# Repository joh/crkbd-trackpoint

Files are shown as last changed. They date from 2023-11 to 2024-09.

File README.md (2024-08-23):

# crkbd trackpoint

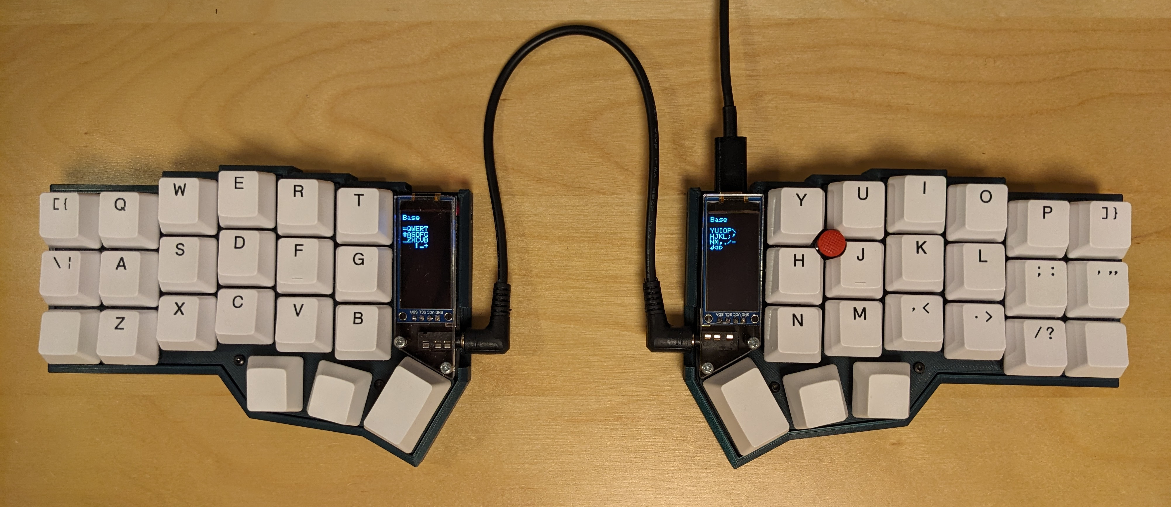
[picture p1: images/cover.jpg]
crkbd trackpoint


I added a trackpoint to a [corne-cherry](https://github.com/foostan/crkbd) (crkbd) keyboard for ergonomic pointing bliss.

The trackpoint is mounted in the middle of the YUHJ keys for easy access from the home row.
Luckily, the corne-cherry PCB has a mounting hole at this exact location, which we repurpose for the trackpoint.

## Hardware
- [corne-cherry kit](https://github.com/foostan/crkbd)
- [Sprintek SK8707 trackpoint module](https://www.sprintek.com/en/products/pointing_stick/SK8707-06.aspx)
- Suitable trackpoint stem
- RP2040 controller, e.g., [SparkFun Pro Micro - RP2040](https://www.sparkfun.com/products/18288) or [Adafruit KB2040](https://www.adafruit.com/product/5302)
- 64x128 OLED module (SH1107)
- 3D-printed case, switch plates, tenting legs (optional) and wrist rest (optional)
- Keycaps

### SK8707 trackpoint module
Can be ordered directly from Sprintek by [sending them an email](https://www.sprintek.com/en/order/Order.aspx).
There is a 5V and 3.3V version.
Get the 3.3V version to be compatible with the RP2040.
I accidentally ordered the 5V version, so I had to bypass the 5V regulator and hooked up 3.3V from the RP2040 to Vout on the board (see photo below).

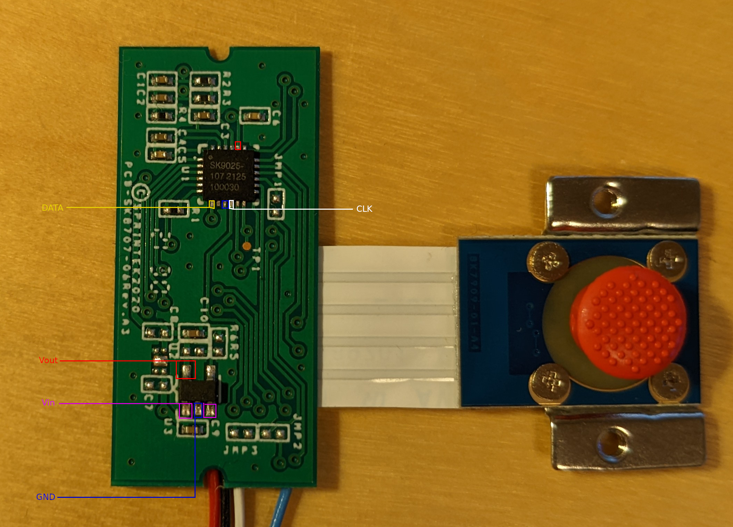
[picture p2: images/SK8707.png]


I desoldered the ribbon cable from the controller board, and wired up only the four wires needed:
- Pin 1: PS/2 data line (blue)
- Pin 6: PS/2 clock line (white)
- Pin 7: GND (black)
- Pin 8: 3.3V (red, if you got the 3.3V version)
- Vout: 3.3V (red, if you got the 5V version)

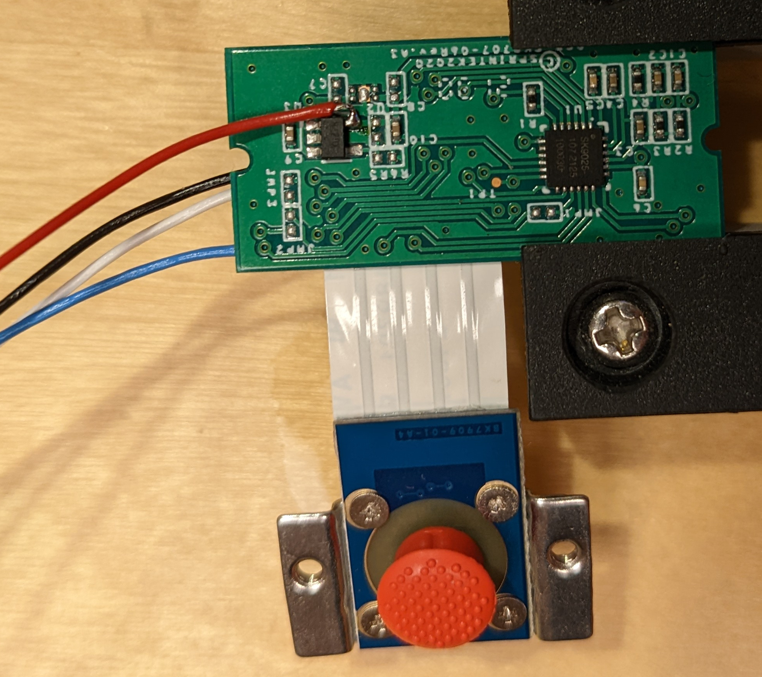
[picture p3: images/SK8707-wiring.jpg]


SK8707 does not require a reset circuit, but it does need pullups on the PS/2 data and clock lines. We can enable pullups on the RP2040 controller, so no extra resistors are needed (see [this commit](https://github.com/joh/qmk_firmware/commit/aa0214f5b1b3001cf7cc99419c32c8b87707cb5a)).

I was lucky to have a trackpoint stem from a decommissioned Tex Yoda II, but others report success using a [labret cheek piercing](https://github.com/alonswartz/trackpoint#q-what-should-i-use-for-the-trackpoint-stemstick).

### RP2040 controller
At first I tried using an AVR-based controller (Elite C with ATMega32U4).
The crkbd occupies the USART pin (D2) for soft serial, so we're stuck with QMKs PS/2 interrupt mode (unless we hack the PCB).
Unfortunately, I found that quite frequently PS/2 packets would arrive with parity errors.
After some investigation, I was able to track it down to [QMK interrupts sometimes being delayed and missing the PS/2 clock altogether](https://www.reddit.com/r/olkb/comments/xppdsz/ps2_interrupt_delays_on_avr/).

Instead of hacking the PCB, it's much easier to upgrade the controller.
This also leaves ample room for other features.
There are several options that are pin-compatible with the Pro Micro.
The RP2040-based boards are not only powerful, but come with Programmable IO (PIO) hardware blocks.
PIO enables protocols such as PS/2 to be implemented in hardware, offloading the main processor for more important work.
A PS/2 PIO driver is now available in QMK (developed by @gamelaster and myself, see [PR #17893](https://github.com/qmk/qmk_firmware/pull/17893)).

Make the following connections from the SK8707:
* PS/2 data line: connect to pin 8 on the RP2040
* PS/2 clock line: connect to pin 9 on the RP2040
* 3.3V and GND are readily available from the OLED header

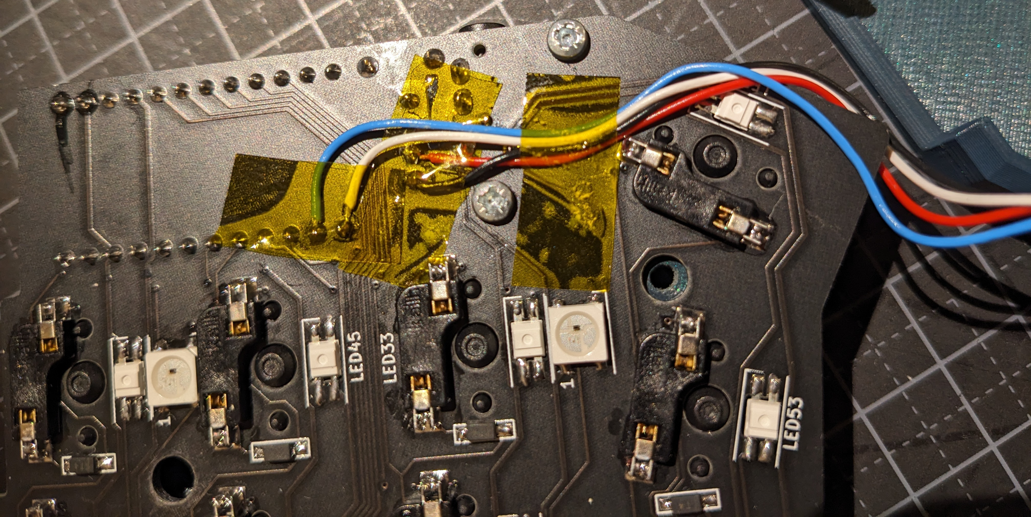
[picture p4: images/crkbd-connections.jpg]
crkbd connections


### 64x128 OLED module (SH1107)

While not directly related to the trackpoint, I upgraded to larger 64x128 OLED modules (SH1107).
These are wide enough so that the entire keymap can be displayed (reflecting the current layer), which is extremely handy.
I also use them to display the current trackpoint sensitivity.
Search AliExpress and you will find plenty of options.

### 3D-printed case

To mount the trackpoint, I designed a 3D-printed case based on the [Travel Crkbd magnetic case by taksi_kavausuki](https://www.printables.com/model/117598-travel-crkbd-magnetic-case).
There is one version of the case without trackpoint (for the left half) and one version with the trackpoint mount (for the right half).
The switch plates are remixed from [Corne Keyboard HiPro Case by mburrows](https://www.thingiverse.com/thing:3652379).

STLs and sources can be found under `STLs/` and `sources/`, respectively.

Some notable features:
* Trackpoint mount (for the right half)
* Insets for 8mm anti-slip pads
* Attachable tenting legs (optional)
* Attachable wrist rests (optional)

STLs:
* `Case_Trackpoint.stl`: Case with trackpoint mount (right half)
* `Case_Normal.stl`: Case without trackpoint mount (left half)
* `Switch_Plate_Trackpoint.stl`: Switch plate for trackpoint
* `Switch_Plate_Normal.stl`: Switch plate without trackpoint
* `Wrist_Rest.stl`: Wrist rest (optional)
* `Leg_50mm.stl` and `Leg_42_5mm.stl`: Tenting legs (optional)

#### Required hardware
* 9x M2 heated inserts
* 9x M2x10 screws
* 2x M2x4 screws
* 2x M2 nuts
* 8x M3nS square nuts (tenting legs and wrist rests)
* 10x M3x10 screws (tenting legs and wrist rests)
* 2x M3 heated inserts (tenting legs on wrist rests)
* 8mm anti-slip pads

#### Printing instructions
Print the parts in your favorite material.
I used PLA with 0.15mm layer height, 4 perimeters and 15% infill.

`Case_Trackpoint.stl` should be printed with supports below the trackpoint mount (add a support enforcer modifier).
For `Wrist_Rest.stl`, add some extra infill around the heated insert (add an infill modifier).

**NB: The parts are all oriented for the left half, so to print the right halves simply mirror each part accordingly in the slicer.**

#### License

The 3D-printed files are licensed under [CC BY-NC-SA 4.0](https://creativecommons.org/licenses/by-nc-sa/4.0/)
[](https://creativecommons.org/licenses/by-nc-sa/4.0/)

### Assembly

The instructions below are for the trackpoint version of the case.

Using a soldering iron, insert the M2 heated inserts into the case:
case trackpoint top

If you would like to use tenting legs, insert M3ns square nuts in the two slots on the left side inside the case.
If you plan on attaching wrist rests, insert M3ns square nuts in the two slots on the bottom side inside the case.
Tip: Use a M3 screw to pull the nuts in.

Turn the case over and insert two M2 nuts for mounting the trackpoint:
case trackpoint bottom

In the above photo you can see the insets for the anti-slip pads.
Attach as many as appropriate (if tenting, you only need pads along the outer edge).

Attach the SK8707 trackpoint module with two M2x4 screws:
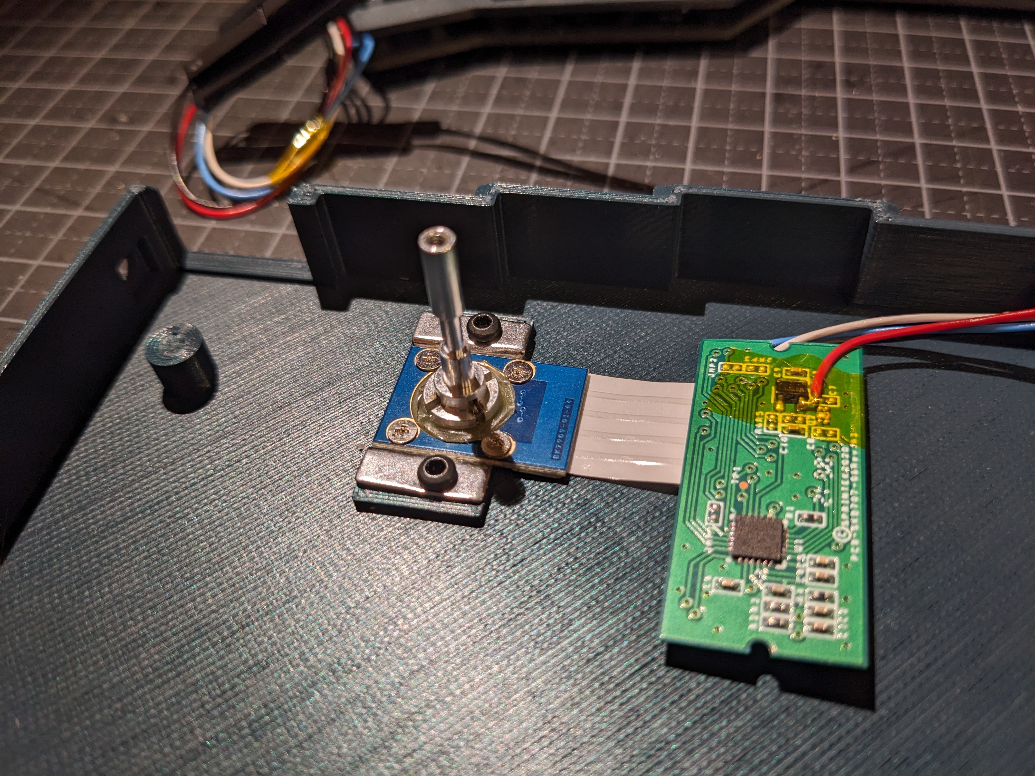
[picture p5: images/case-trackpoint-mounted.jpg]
case trackpoint mounted


Attach the SK8707 PCB with double-sided tape, and route the wires as follows:
case trackpoint wiring

Insert the crkbd PCB with the 3D-printed switch plate and attach with four M2x10 screws.
Make sure the trackpoint wires are not pinched!
Note: the PCB switch plate and bottom plate that come with the corne cherry kit are not used.
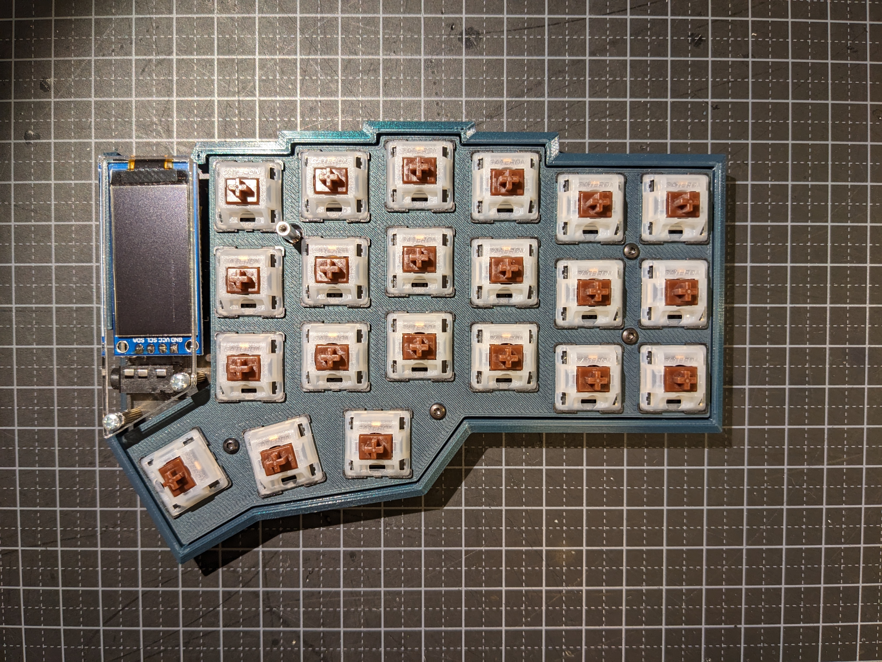
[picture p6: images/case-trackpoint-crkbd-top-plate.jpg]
case trackpoint wiring


The YUHJ keycaps must be modified to make room for the trackpoint stem (see below for jig).
Here the stem sports a 3D-printed adapter for the trackpoint cap.
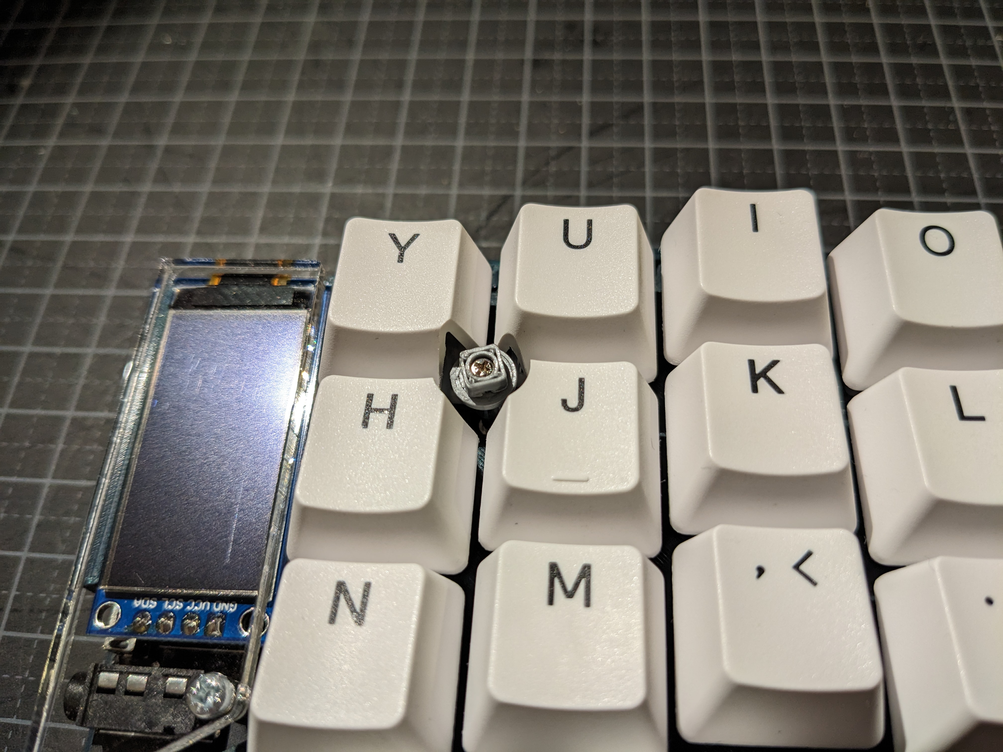
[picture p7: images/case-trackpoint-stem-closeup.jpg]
case trackpoint stem closeup


With the cap it looks rather neat:
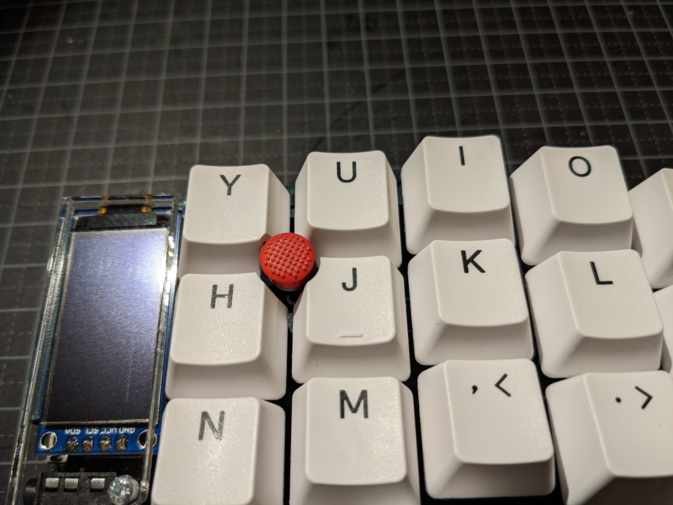
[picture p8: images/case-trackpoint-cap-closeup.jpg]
case trackpoint cap closeup


The finished product:
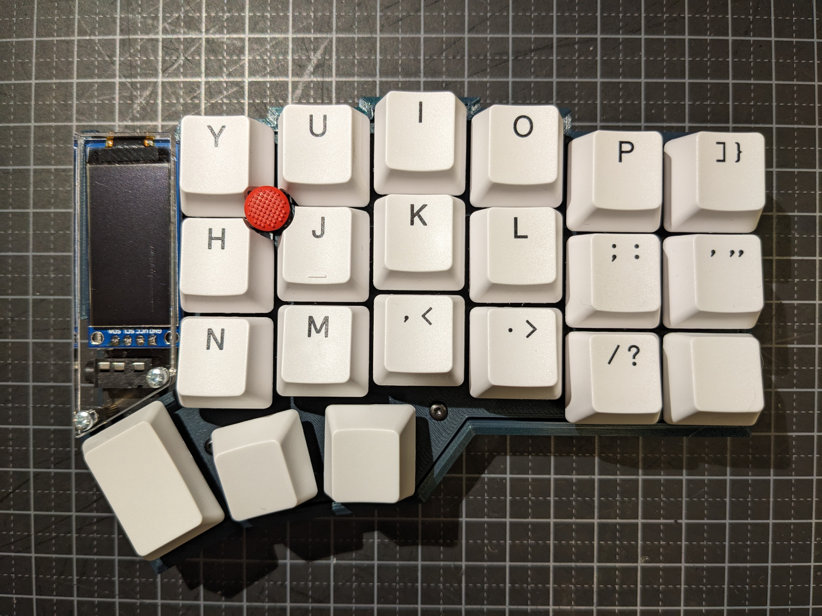
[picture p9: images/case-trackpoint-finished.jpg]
case trackpoint finished


Repeat the above process for the other half (excluding the trackpoint, of course).

Tenting legs can be customized to any height in OpenSCAD, and attach to the side of the keyboard:
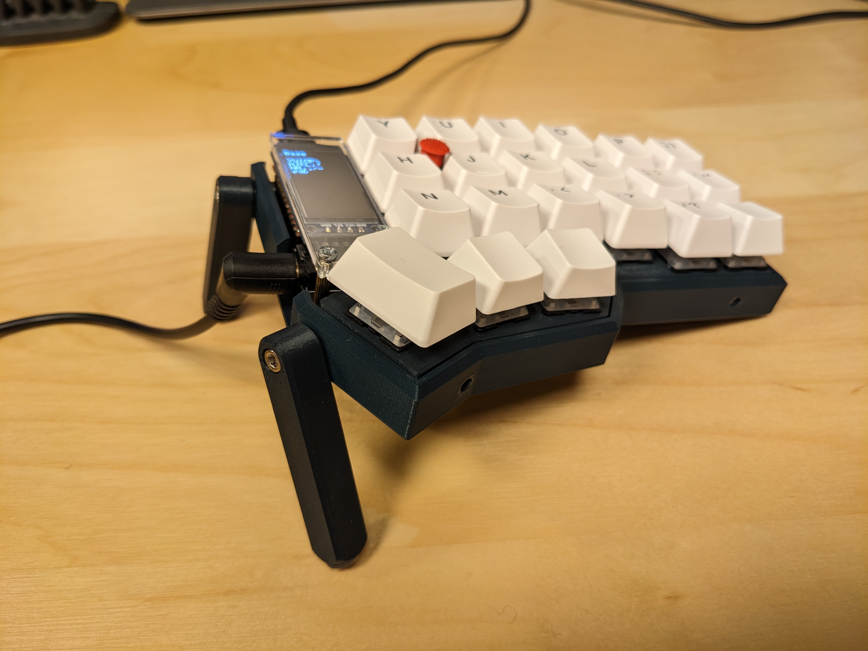
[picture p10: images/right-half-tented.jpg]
crkbd trackpoint tented


Using the trackpoint is most comfortable using a wrist rest.
The wrist rest also helps prevent the keyboard from being pushed across the desk while using the trackpoint.
For comfort, I attached some 5mm neoprene pads.
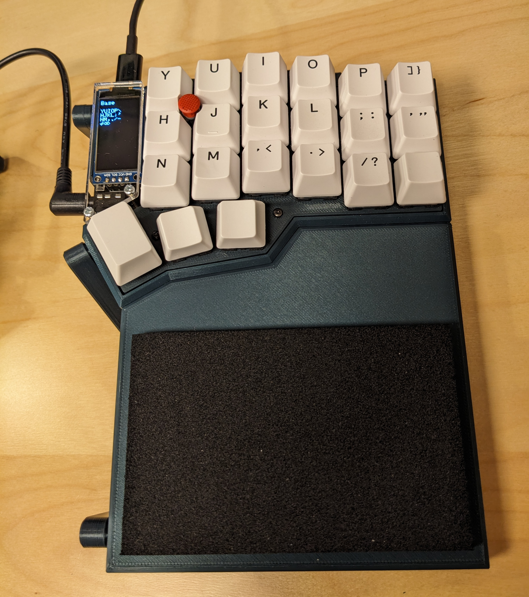
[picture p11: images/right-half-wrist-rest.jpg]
crkbd trackpoint with wrist rest


Both halves with wrist rests and tenting:
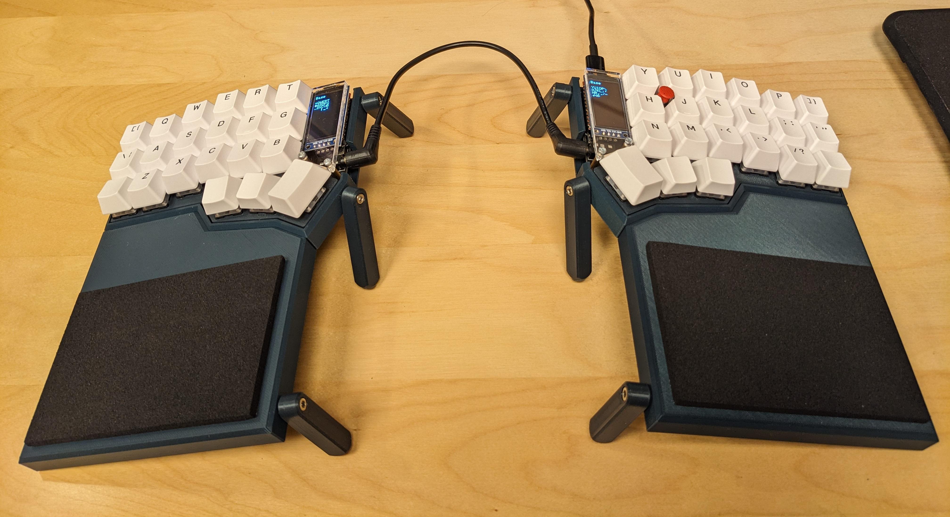
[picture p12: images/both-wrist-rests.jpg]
both halves with wrist rests and tenting


### YUHJ drilling jig

There is also a 3D-printable jig available for help modifying the YUHJ keycaps to accomodate the trackpoint.
Place the YUHJ keys between the top and bottom plate, and fasten the plates together with some screws.
Then use the hole as a guide to file / Dremel away a small part of each key.

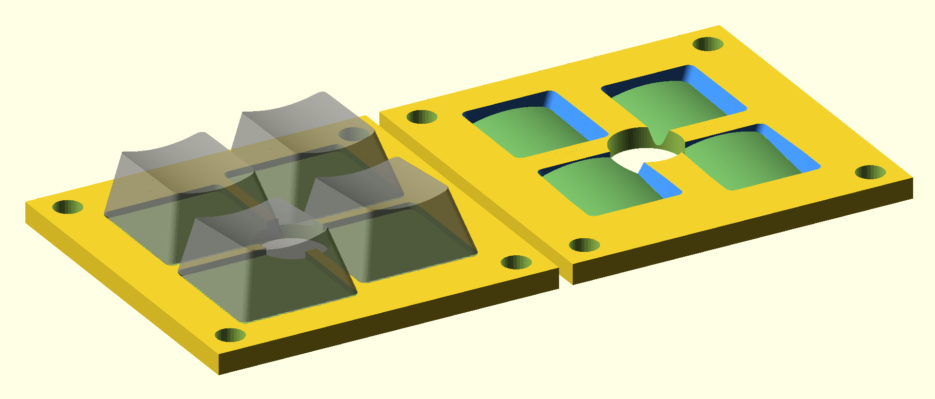
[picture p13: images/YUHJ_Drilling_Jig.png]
YUHJ drilling jig


STLs:
* `YUHJ_Drilling_Jig_Bottom.stl`
* `YUHJ_Drilling_Jig_Top.stl`

The jig can be customized for different keycap profiles, see `YUHJ_Drilling_Jig.scad`.

### Firmware
Please see my [qmk branch](https://github.com/joh/qmk_firmware/tree/joh-rp2040-trackpoint-pio-v4/keyboards/crkbd/keymaps/joh) for details on how to configure QMK.

Some notable features:
* `MH_AUTO_MOUSE_BUTTONS` from manna-harbour is used to automatically switch to the mouse layer when the trackpoint is used.
* Pullups are enabled on the PS2 CLK/DATA pins (see [this commit](https://github.com/joh/qmk_firmware/commit/aa0214f5b1b3001cf7cc99419c32c8b87707cb5a))
* Custom keys for controlling trackpoint sensitivity

## Other resources
This project was largely inspired by manna-harbours [crkbd hotstwap trackpoint](https://github.com/manna-harbour/crkbd).
Other good sources of information:
* [jorne trackpoint](https://github.com/joric/jorne/wiki/Trackpoint)
* [How to integrate a trackpoint in a mechanical keyboard by alonswartz](https://github.com/alonswartz/trackpoint)
* [TPS42 keyboard](https://kbd.news/TPS42-1711.html)

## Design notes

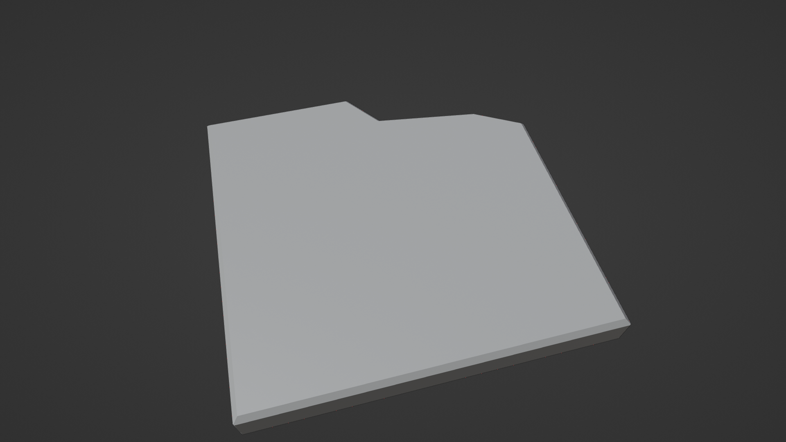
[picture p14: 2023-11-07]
images/Wrist_Rest.png

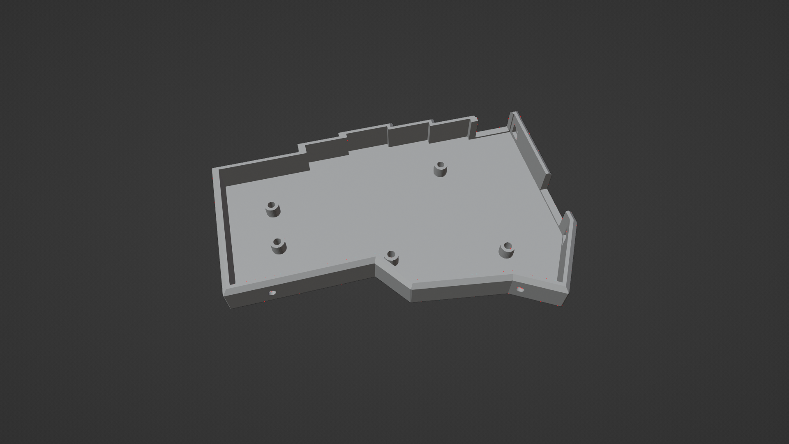
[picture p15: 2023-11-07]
images/Case_Normal.png

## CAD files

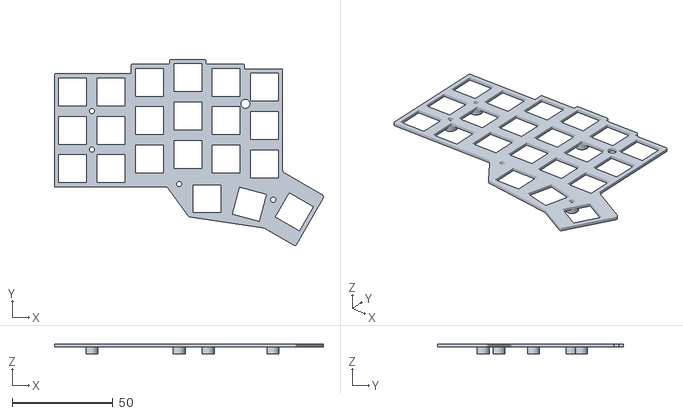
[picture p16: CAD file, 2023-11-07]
STLs/Switch_Plate_Trackpoint.stl
133.2 x 92.2 x 4.90

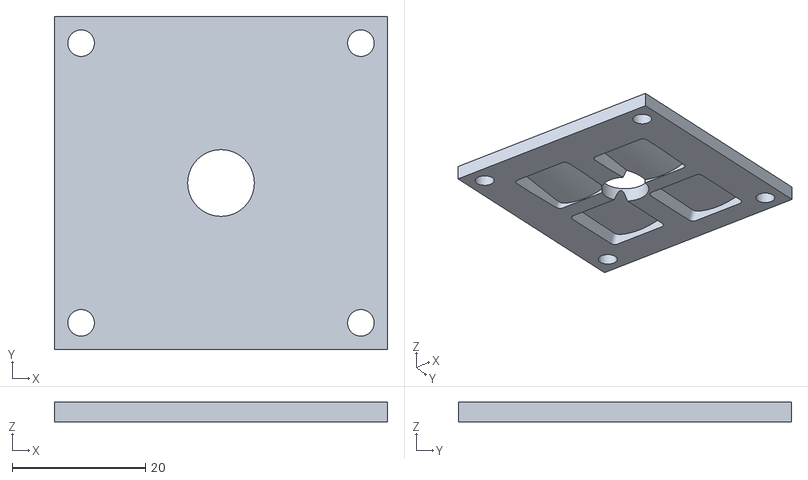
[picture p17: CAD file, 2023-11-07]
STLs/YUHJ_Drilling_Jig_Top.stl
50.0 x 50.0 x 3.00

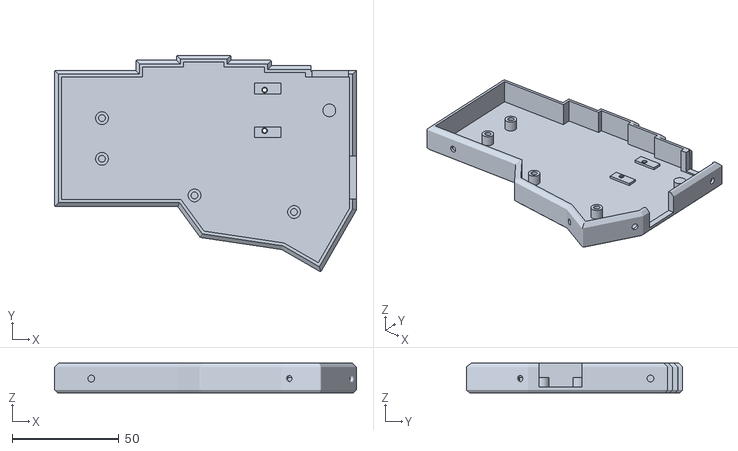
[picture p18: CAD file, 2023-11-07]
STLs/Case_Trackpoint.stl
141.2 x 101.1 x 13.8

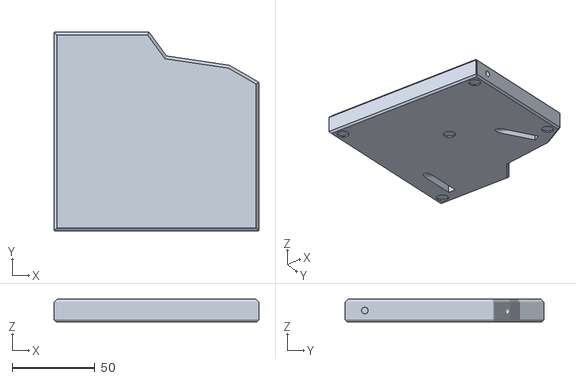
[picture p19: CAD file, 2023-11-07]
STLs/Wrist_Rest.stl
124.1 x 120.4 x 13.8

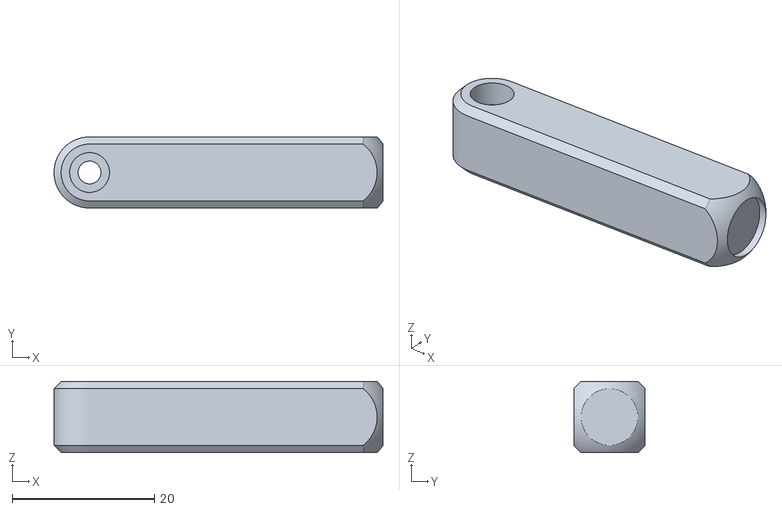
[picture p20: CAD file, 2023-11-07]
STLs/Leg_42_5mm.stl
46.3 x 10.0 x 10.0

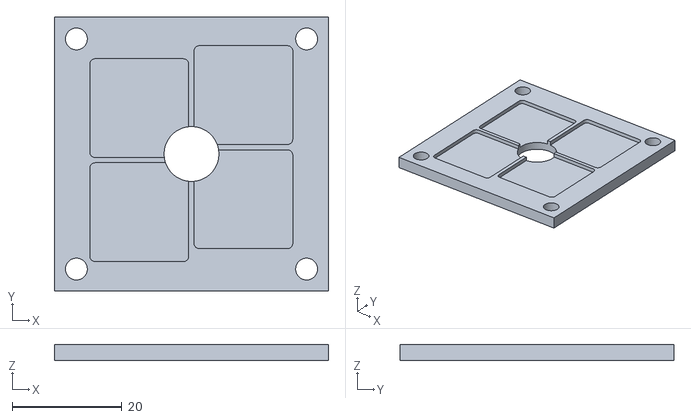
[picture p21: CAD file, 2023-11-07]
STLs/YUHJ_Drilling_Jig_Bottom.stl
50.0 x 50.0 x 3.00

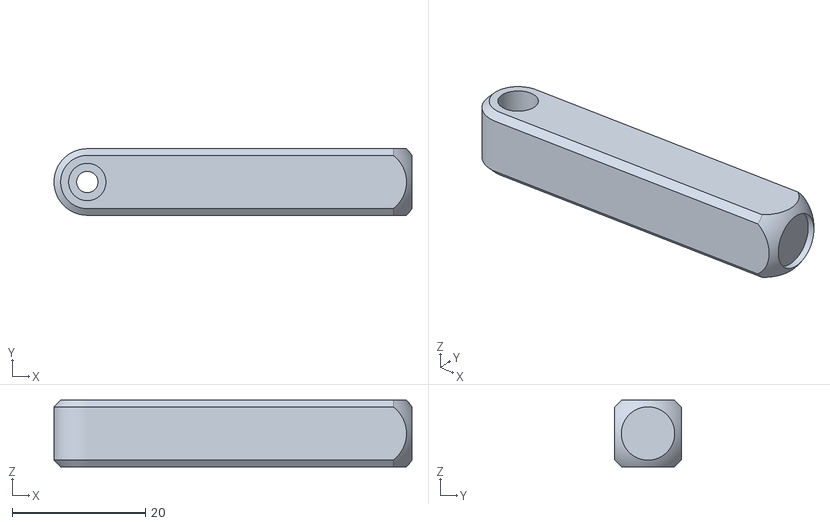
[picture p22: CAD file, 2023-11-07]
STLs/Leg_50mm.stl
53.8 x 10.0 x 10.0

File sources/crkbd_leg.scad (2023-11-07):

/*
 * Tenting leg for crkbd_trackpoint_case
 */
include <Chamfers-for-OpenSCAD/Chamfer.scad>;

// Leg thickness (height)
thickness=10;

// Leg length (from screw center to bottom, including pad)
length=42.5;

// Diameter of screw hole
screw_dia=3.2;

// Diameter of screw head inset
screw_head_dia=5.6;

// Depth of screw head inset
screw_head_inset=thickness - 6.8;

// Diameter of anti-slip pad
pad_dia=8;

// Depth of inset for anti-slip pad
pad_depth=1;

// Chamfer
ch = 1;

$fn=360;

difference() {
    r = max(screw_head_dia/2 + 2, thickness/2);
    d = sqrt(2)*thickness;
    chamfers = [[1, 1, 1, 1], [0, 0, 0, 0], [0, 0, 0, 0]];
    union() {
        chamferCylinder(h=thickness, r=r, ch=ch);
        translate([0, -thickness/2, 0])
            chamferCube([length-thickness/2, thickness, thickness], chamfers, ch);

        translate([length-d/2, 0, thickness/2])
        intersection() {
            sphere(d=d);
            translate([0, -thickness/2, -thickness/2])
            chamferCube([thickness, thickness, thickness], chamfers, ch);
        }
    }

    translate([0, 0, thickness-screw_head_inset])
        cylinder(h=100, d=screw_head_dia);
    cylinder(h=100, d=screw_dia, center=true);

    s = (d/2) - sqrt((d/2)^2 - (pad_dia/2)^2);
    translate([(length-s-pad_depth), 0, thickness/2])
    rotate([0, 90, 0])
        cylinder(h=100, d=pad_dia);
}

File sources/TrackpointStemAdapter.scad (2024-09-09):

cube_width        = 4.3; // measured: 4.5
cube_height       = 2.4; // measured: 2.4
base_dia          = 7.0; // measured: 7.0
base_height       = 3.6; // measured: 0.6
bottom_hole_dia   = 3.3; // measured: 3.1
bottom_hole_depth = 2.0; // measured: 2.0
hole_dia          = 2.0; // measured: 1.8
screw_head_dia    = 2.7; // measured: 2.5
screw_head_depth  = 3.0; // measured: 3.0

$fn = 60;

difference() {
union() {
translate([-cube_width/2, -cube_width/2, base_height])
cube([cube_width, cube_width, cube_height]);

cylinder(d=base_dia, h=base_height);
}

translate([0, 0, -bottom_hole_depth])
cylinder(d=bottom_hole_dia, h=2*bottom_hole_depth);

cylinder(d=hole_dia, h=10);

translate([0, 0, screw_head_depth])
cylinder(d=screw_head_dia, h=10);
}

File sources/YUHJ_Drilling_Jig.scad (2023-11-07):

// the point of this file is to be a sort of DSL for constructing keycaps.
// when you create a method chain you are just changing the parameters
// key.scad uses, it doesn't generate anything itself until the end. This
// lets it remain easy to use key.scad like before (except without key profiles)
// without having to rely on this file. Unfortunately that means setting tons of
// special variables, but that's a limitation of SCAD we have to work around

include <./KeyV2/includes.scad>


// example key
/*dcs_row(5) legend("⇪", size=9) key();*/

// example row
/* for (x = [0:1:4]) {
  translate_u(0,-x) dcs_row(x) key();
} */

// example layout
//preonic_default("oem") key();
//60_percent_default("oem") key();
/*translate([0, $unit/2, 0])*/
/*planck_default("oem") key();*/

// The stem is the hardest part to print, so this variable controls how much 'slop' there is in the stem
// if your keycaps stick in the switch raise this value
//$stem_slop = 0.35; // Not working in thingiverse customizer atm [0:0.01:1]
// broke this out. if your keycaps are falling off lower this value. only works for cherry stems rn
$stem_inner_slop = 0.25;
$stem_inset = 0;

$unit = 19;
$dy = 2.38;

plate_size = 50;
plate_thickness = 3;
plate_hole = 4;

module plate_hole() {
    cylinder(d=plate_hole, h=100, center=true);
}

module plate_holes() {
    translate([-plate_size/2 + plate_hole, plate_size/2 - plate_hole, 0])
    plate_hole();

    translate([-plate_size/2 + plate_hole, -plate_size/2 + plate_hole, 0])
    plate_hole();

    translate([plate_size/2 - plate_hole, -plate_size/2 + plate_hole, 0])
    plate_hole();

    translate([plate_size/2 - plate_hole, plate_size/2 - plate_hole, 0])
    plate_hole();
}

module plate() {
    translate([-plate_size/2, -plate_size/2, 0])
    cube([plate_size, plate_size, plate_thickness]);
}

module top_plate() {
    difference() {
        translate([0, 0, 7])
        plate();
        keys();
        plate_holes();
        trackpoint_hole();
    }
}

module bottom_plate() {
    difference() {
        translate([0, 0, -plate_thickness+1])
        plate();
        keys_slot();
        //keys();
        plate_holes();
        trackpoint_hole();
    }
};

bottom_plate();
translate([plate_size+2, 0, 8])
rotate([0,180,0])
top_plate();
color("gray", .75)
keys();

module keys_slot() {
    linear_extrude(height=4, convexity=2)
    projection()
    keys();
}

module keys() {
    union() {
        translate([-9.54, 8.37, 0])
        //oem_row(1) legend("Y") key();
        oem_row(1) outer_total_shape(false);

        translate([9.47, 10.75, 0])
        //oem_row(1) legend("U") key();
        oem_row(1) outer_total_shape(false);

        translate([-9.53, -10.62, 0])
        //oem_row(2) legend("H") key();
        oem_row(2) outer_total_shape(false);

        translate([9.47, -8.25, 0])
        //oem_row(2) legend("J") key();
        oem_row(2) outer_total_shape(false);
    }
};

module trackpoint_hole() {
    cylinder(d=10, h=40, center=true, $fn=90);
}

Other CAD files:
STLs/Switch_Plate_Normal.stl
STLs/Case_Normal.stl
sources/crkbd_trackpoint_case.blend

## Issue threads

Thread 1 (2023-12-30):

It works until the keyboard gets disconnected, then it is hit and miss whether it will start working again.

BenBKirk, 2023-12-30:
Hi Joh,

Thank you for uploading this guide, I wouldn't have been able to get my trackpoint working without it.

Here is a picture of my Corne with the trackpoint placed in the thumb position:
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

I upgraded to RP2040 with the following pinout:
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

Flashing your keymap straight into the keyboard made everything work but when I unplug the keyboard, or the computer sleeps or I reset the board, it becomes unresponsive. This happens on windows 11 and arch linux. From the OS the device is still connected, it just doesn't do anything. As if it crashed but the green light stays on the microcontrollers. If I then reset the board a few times it connects every 5 tries or so and everything works fine including the trackpoint, until I disconnect the keyboard or shutdown the laptop.

Have you ever experienced a similar issue?
The only difference that I can see between our builds is that I am using a different trackpoint and I have made a small reset circuit for it by following this guide https://rfong.github.io/rflog/2021/10/26/r61-trackpoint-pt2/ .

Would appreciate any input for how I could troubleshoot this.

Thanks,
Ben

joh, 2024-01-03:
Hi, looks like a clean build! I have not experienced the issue you're describing, but here's a few things to try:

1. Does it work with the trackpoint disabled? (set `TRACKPOINT_ENABLE = no` in `keyboards/crkbd/keymaps/joh/rules.mk`)
2. If not, does it work if you disconnect the trackpoint clock and data wires?
3. I believe your trackpoint module (R61) is 5V I/O, but the RP2040 is 3.3V and the GPIO pins cannot safely handle 5V. You need a level shifter between the trackpoint CLK/DATA lines and the RP2040 GPIO pins.

BenBKirk, 2024-01-10:
Thanks for the advice.
I had already unsoldered the trackpoint by the time you replied and as expected there was no more crashing even without changing anything in the code.
I was under the impression that a 5v trackpoint would still work at 3.3v as mentioned [here](https://github.com/joric/jorne/wiki/Trackpoint#t60t400-trackpoint) but what you are saying makes sense, maybe I should look for a 3.3V trackpoint module.

Something also worth mentioning, I also have pull-up resistors for data and clock wires but noticed that you did this in the code somewhere instead. how did you do this and do I need to disable it?

joh, 2024-01-11:
> I was under the impression that a 5v trackpoint would still work at 3.3v as mentioned [here](https://github.com/joric/jorne/wiki/Trackpoint#t60t400-trackpoint) but what you are saying makes sense, maybe I should look for a 3.3V trackpoint module.

I'm not sure I understand what that page says about 3.3V. Does it say 5V and 3.3V logic levels are compatible? Or perhaps powering the R61 off 3.3V should work?

> Something also worth mentioning, I also have pull-up resistors for data and clock wires but noticed that you did this in the code somewhere instead. how did you do this and do I need to disable it?

You're right, two pullups could be causing problems. The 3.3V pullup was added in [aa0214f](https://github.com/joh/qmk_firmware/commit/aa0214f5b1b3001cf7cc99419c32c8b87707cb5a). You can try reverting that commit, keeping your external pullup (`git revert aa0214f`)

joh, 2024-08-23:
Closing due to inactivity.

Closed 2024-08-23.

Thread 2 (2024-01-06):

Where are pins B4 and B5 on the RP2040? For the PS/2 clock and data lines.

bluepylons, 2024-01-06:
The README states the following for the Trackpoint connections:

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

What pins are these referring to? I can't find any RP2040 boards with that pin naming scheme. Is B4 GPIO 9 (which is PWM4B), and is B5 GPIO 11 (which is PWM5B)?

joh, 2024-01-11:
Hi, sorry that's confusing. Those refer to the corresponding pins on a regular pro micro. There is a [_pin_defs.h](https://github.com/joh/qmk_firmware/blob/joh-rp2040-trackpoint-pio-v4/keyboards/crkbd/keymaps/joh/_pin_defs.h) which maps them to the RP2040. In any case, B4 and B5 correspond to pins 8 and 9. I'll update the README :)

Closed 2024-01-11.

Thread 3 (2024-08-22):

[QUESTION] pullups on the RP2040

tcastelly, 2024-08-22:
Hi,

Thank you very much for this documentation!

I'm confuse with one thing:
```txt
SK8707 does not require a reset circuit, but it does need pullups on the PS/2 data and clock lines. We can enable pullups on the RP2040 controller, so no extra resistors are needed.
```

What have I to do exactly?

Thank you again.

joh, 2024-08-23:
Hi, I added a link to the commit which enables the pullups to the README :)

tcastelly, 2024-08-24:
Thank you very much for your answer :)

Do we have to apply this change for all SK8707 models, or is it because you have a 5V one?

Thx again.

joh, 2024-08-24:
Yes, pullups are needed regardless of the voltage level (5V/3.3V).

Closed 2024-08-23.

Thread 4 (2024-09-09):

Trackpoint stem Tex Yoda II dimensions

philippbaumm, 2024-09-09:
Hey joh,

Could you please provide some dimensions for the Tex Yoda II stem and any other related components you utilized for your build? I'd like to contribute step files for this.

I'm interested in adding your mod to my Corne keyboard, but using a piercing as a substitute doesn't appeal to me.

Thanks in advance!

joh, 2024-09-09:
Sure, below are some pictures with measurements of the stem. The top of the stem is threaded with M1.6(?), where there's an adapter for the TrackPoint cap. For the crkbd mod the one that came with the Tex Yoda II was not tall enough, so I printed a taller one. See sources/TrackpointStemAdapter.scad

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

philippbaumm, 2024-09-09:
Thank you so much, joh! This is exactly what I needed. Much appreciated. Your mod is really cool, and I'm excited to try adapting it for my corne. Thanks again for sharing your work!

joh, 2024-09-09:
You're welcome! Good luck with your mod :) Feel free to post some pictures here with your progress 👍

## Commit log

2024-09-09 Add stem adapter (for the Tex Yoda II stem)
    Fastened to the top of the stem to accommodate the trackpoint cap
    [TrackpointStemAdapter.scad]
2024-09-09 Move stem adapter to sources
    [TrackpointStemAdapter.scad]

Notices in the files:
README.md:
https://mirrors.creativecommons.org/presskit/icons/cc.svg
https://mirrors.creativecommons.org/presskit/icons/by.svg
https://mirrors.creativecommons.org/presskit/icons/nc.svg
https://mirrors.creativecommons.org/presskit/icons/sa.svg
